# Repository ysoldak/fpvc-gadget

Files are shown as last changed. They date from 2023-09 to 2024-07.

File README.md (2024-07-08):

# FPV Combat Gadget

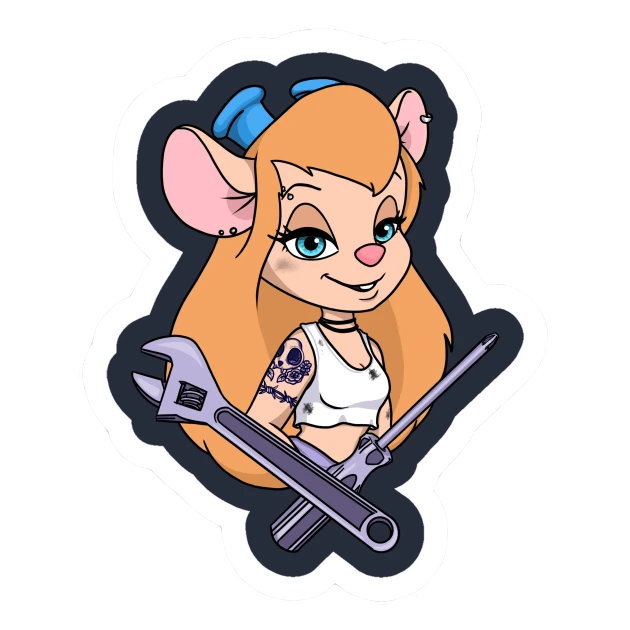
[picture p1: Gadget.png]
Gadget to your service


DIY device (gadget) that helps you quickly adjust [FPV Combat](https://www.fpv-combat.com) board settings like player ID, player name, lives, ammo and many more.

This is an alternative to classic way of using OSD menu (and IR remote earlier).  
It is a convenient way to adjust settings "on the go", at the field, for everyone.

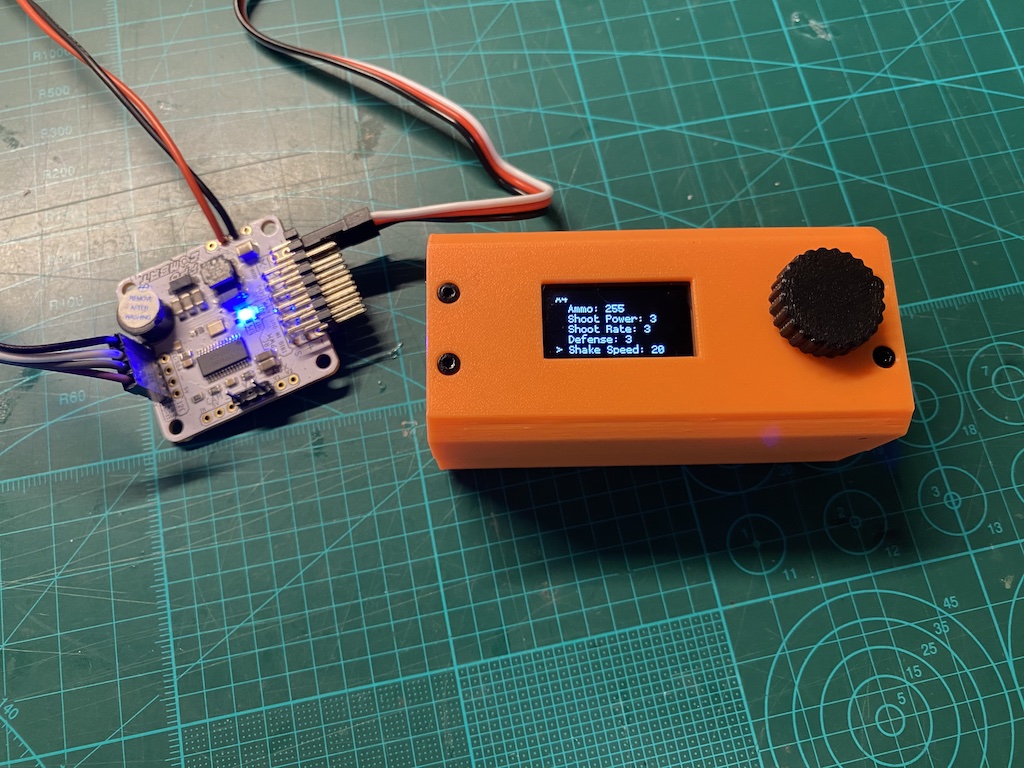
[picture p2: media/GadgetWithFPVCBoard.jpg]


FPV Combat board shall be flashed with compatible [firmware](https://github.com/FPV-Combat/Main_board_v2/releases).

**Gadget version 0.5.0+ requires FPV Combat version 2.8.0+.**

## Electronic Components

You'll need to buy some electronic components and 3D print the case, see below.  
Soldering skills required.

| Picture  | Item | Comment | Price (per item)  |
| --- | --- | --- | --- |
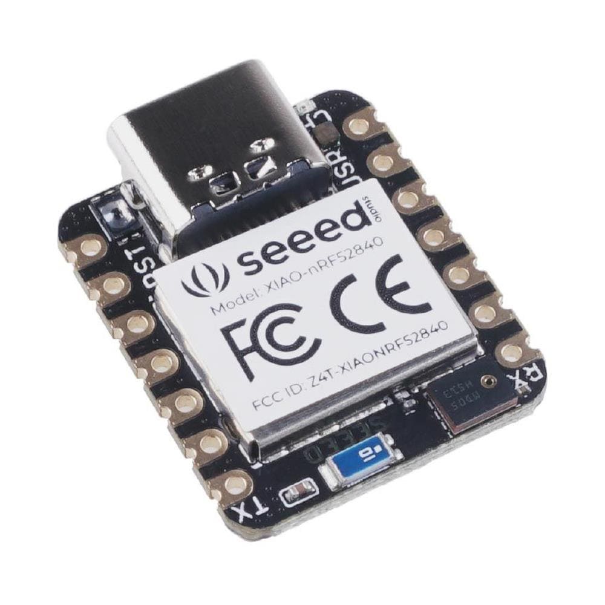
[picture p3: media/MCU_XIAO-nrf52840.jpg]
|  | [XIAO-nRF52840 board](https://www.seeedstudio.com/Seeed-XIAO-BLE-nRF52840-p-5201.html) | With battery charger | [$9.90](https://www.seeedstudio.com/Seeed-XIAO-BLE-nRF52840-p-5201.html) |
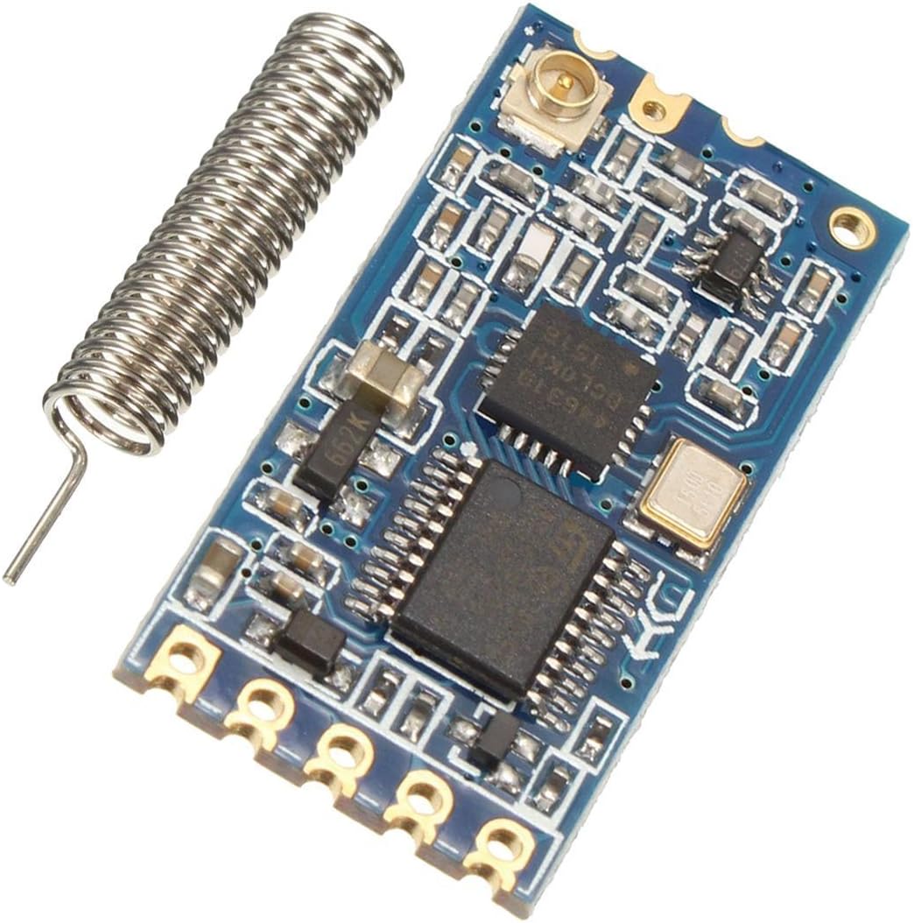
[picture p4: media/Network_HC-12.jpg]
|  | [HC-12 network module](https://www.hc01.com/goods/640e91920be12d0114404c95) | 433Mhz | $12 |
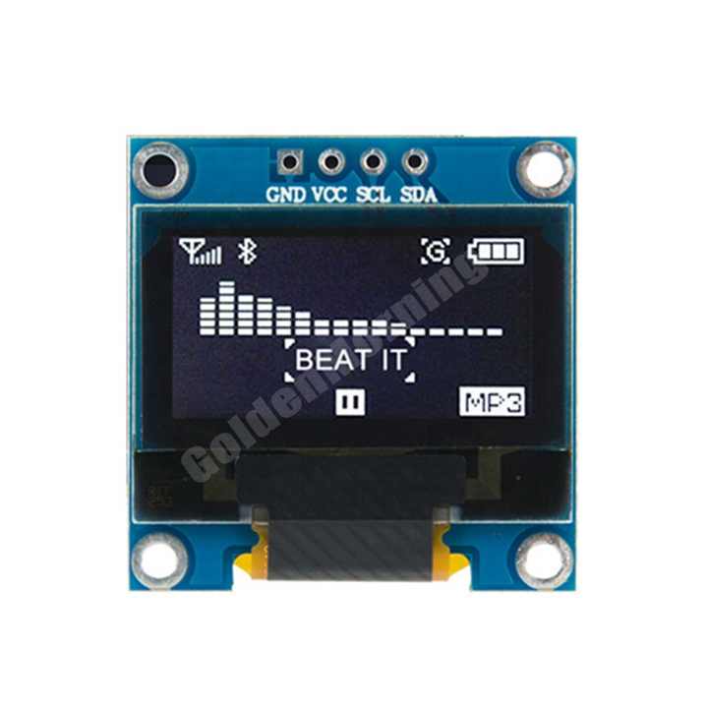
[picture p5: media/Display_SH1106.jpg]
|  | [0.96inch display](https://www.az-delivery.de/en/products/0-96zolldisplay) | OLED 128 x 64 | [$2.4](https://www.alibaba.com/product-detail/Most-Popular-GME12864-White-4pins-I2C_1600270997819.html) - [$3.8](https://www.amazon.se/dp/B074NJMPYJ) |
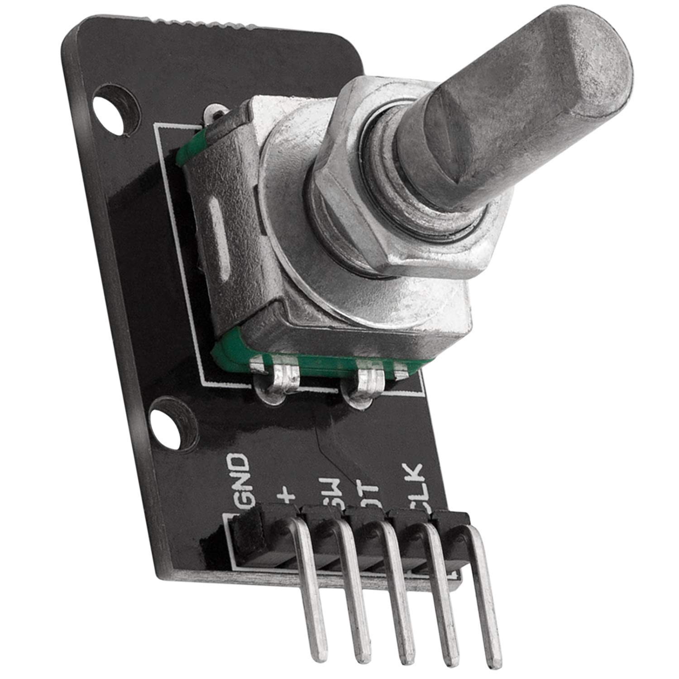
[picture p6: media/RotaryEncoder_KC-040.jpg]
|  | KY-040 rotary encoder | Breakout | [$1.8](https://www.amazon.se/dp/B07TKK4QQD) |
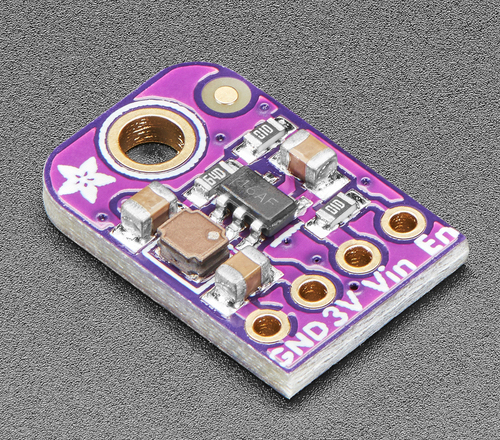
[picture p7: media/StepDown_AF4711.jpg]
|  | [Adafruit TLV62569 (4711)](https://www.adafruit.com/product/4711) | Step-down converter 3.4~5.5V to 3.3V | [$3.95](https://www.digikey.se/sv/products/detail/adafruit-industries-llc/4711/13162412) |
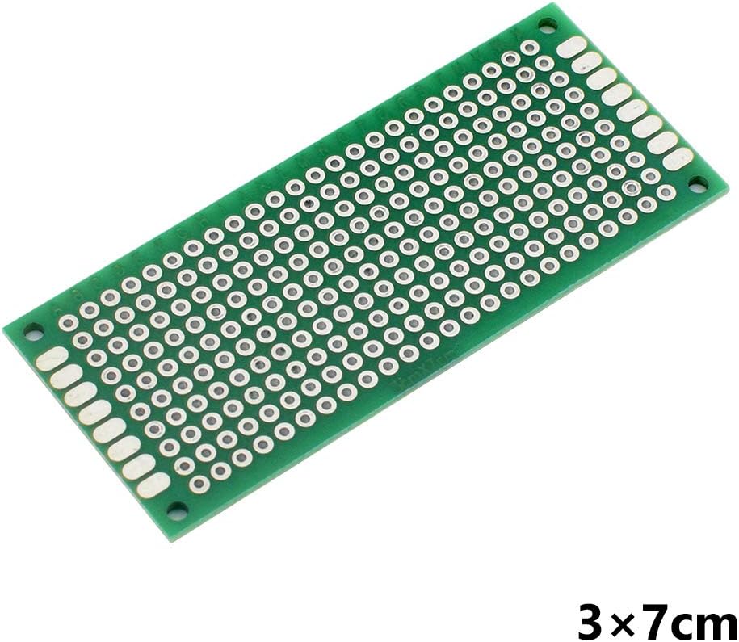
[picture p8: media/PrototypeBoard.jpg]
|  | Prototype board | 30 x 70 mm, or PCB | [$0.8](https://www.amazon.se/dp/B07CQQK214) |
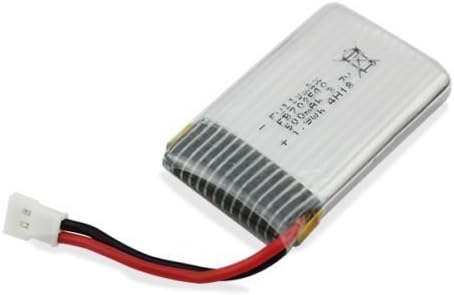
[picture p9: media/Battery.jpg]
|  | LiPo Battery | 1S, 100-500mAh, 45 x 25 x 9 mm | [$11](https://www.amazon.se/dp/B01FBSA1N6/) |
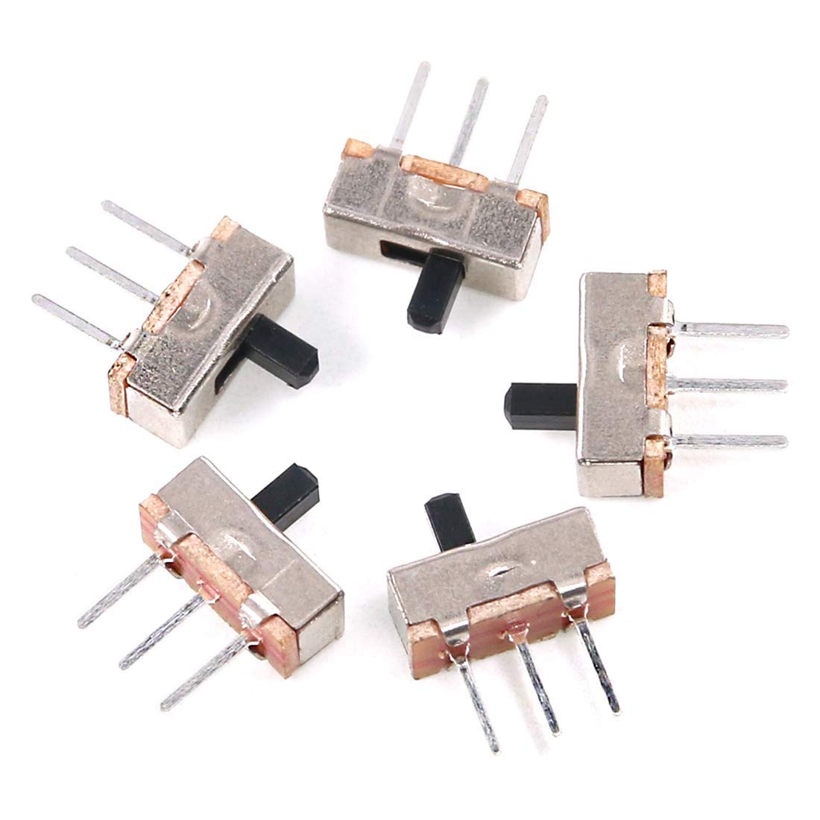
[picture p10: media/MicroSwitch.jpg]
|  | Micro Slide Switch | 2 positions, 3 contacts | [$0.1](https://www.amazon.se/Gebildet-Vertikal-Switch-SS-12d00-Position/dp/B08L6FMV84/?th=1) | 
| **Total** ||| **$45** |

### Alternatives
- MCU
  - [XIAO-RP2040](https://www.seeedstudio.com/XIAO-RP2040-v1-0-p-5026.html) - $5.40 (cheaper, no battery charger)
  - [XIAO-nRF52840 Sense](https://www.seeedstudio.com/Seeed-XIAO-BLE-Sense-nRF52840-p-5253.html) - $15.99 (more expensive, has IMU that we don't use)
- Step-down converter
  - [LM3671](https://www.adafruit.com/product/2745) - $4.95
  - [TPS62827](https://www.adafruit.com/product/4920) - $6.95
  - [DFR0568](https://www.dfrobot.com/product-1765.html) - $2.9
- Battery charger (optional, use with MCU w/o built-in battery charger)
  - [Greluma 6st](https://www.amazon.se/dp/B09WMVLWH5)

## Assembly

It is possible to [order the gadget](https://www.etsy.com/se-en/listing/1589030767/fpv-combat-gadget-battery-not-included) either fully assembled, as a kit or just PCB from [our shop on Etsy](https://www.etsy.com/se-en/shop/SkyGadgets).

Alternatively, you can always order PCB yourself from PCBWay, JLCPCB and alike or use 30x70mm prototype board.

### Assembly tips

- Once soldered, backs of pins/slots have to be filed out/flattened, otherwise risk of damaging the battery;
- Straighten encoder pins and cut them a bit, just a several mm;
- Cut a bit of encoder pcb, across mounting holes, otherwise it does not fit;
- HC-12 is placed white (flat) side up;
- Pull HC-12 antenna a little so it is away from everything to minimise interference.

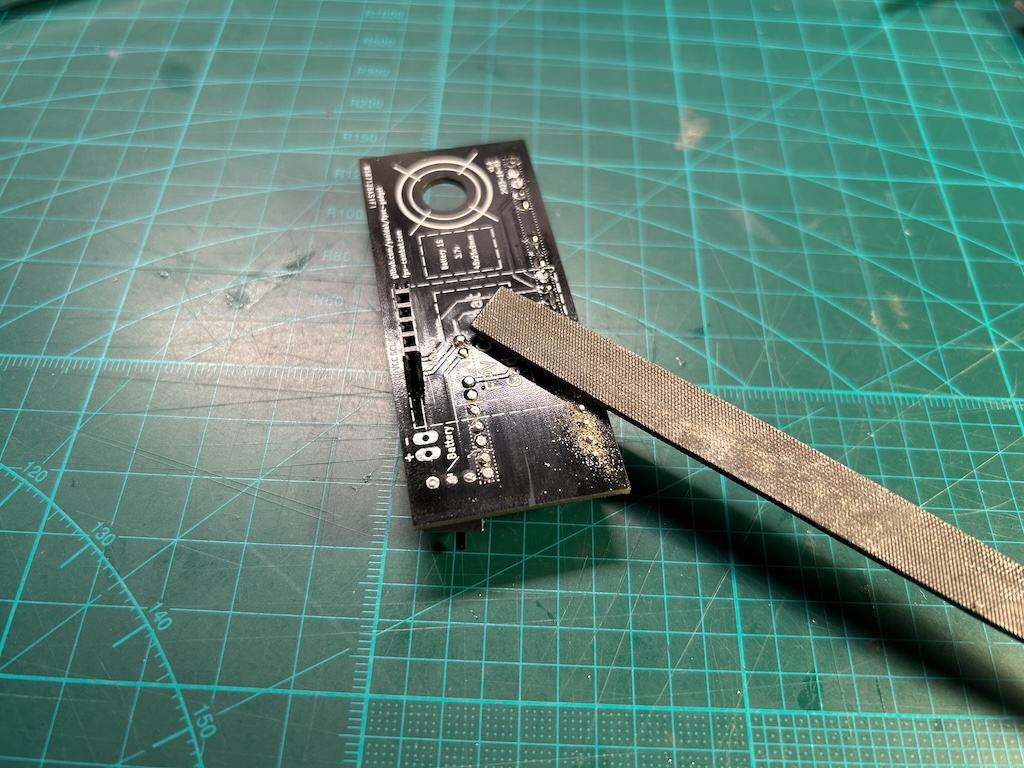
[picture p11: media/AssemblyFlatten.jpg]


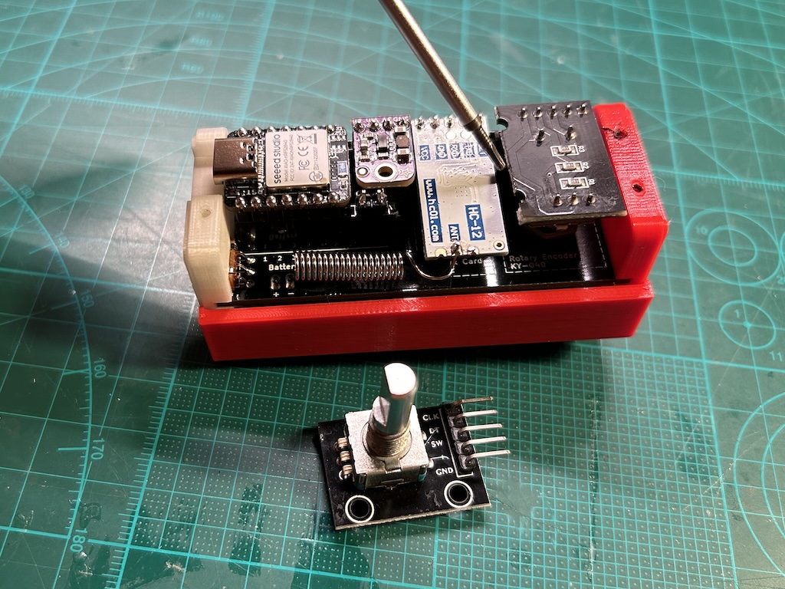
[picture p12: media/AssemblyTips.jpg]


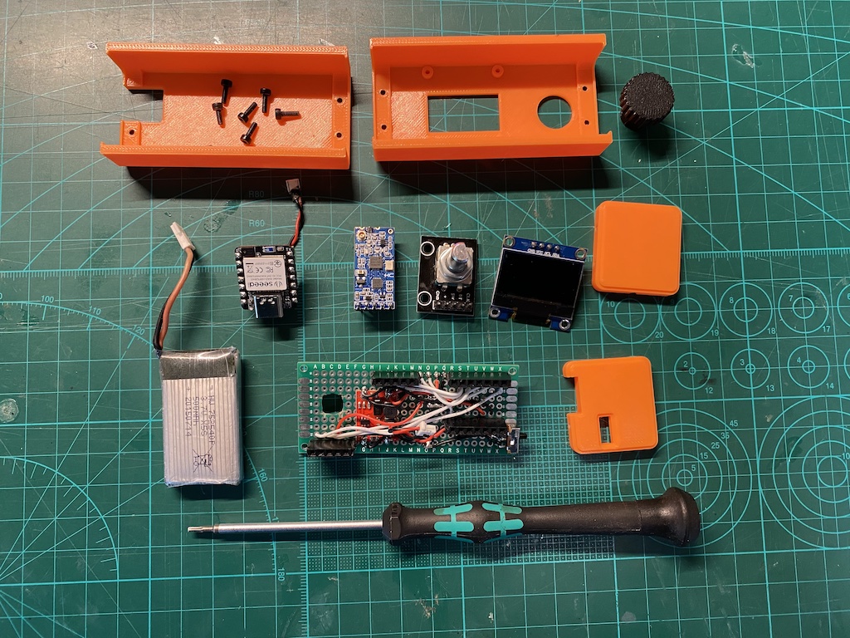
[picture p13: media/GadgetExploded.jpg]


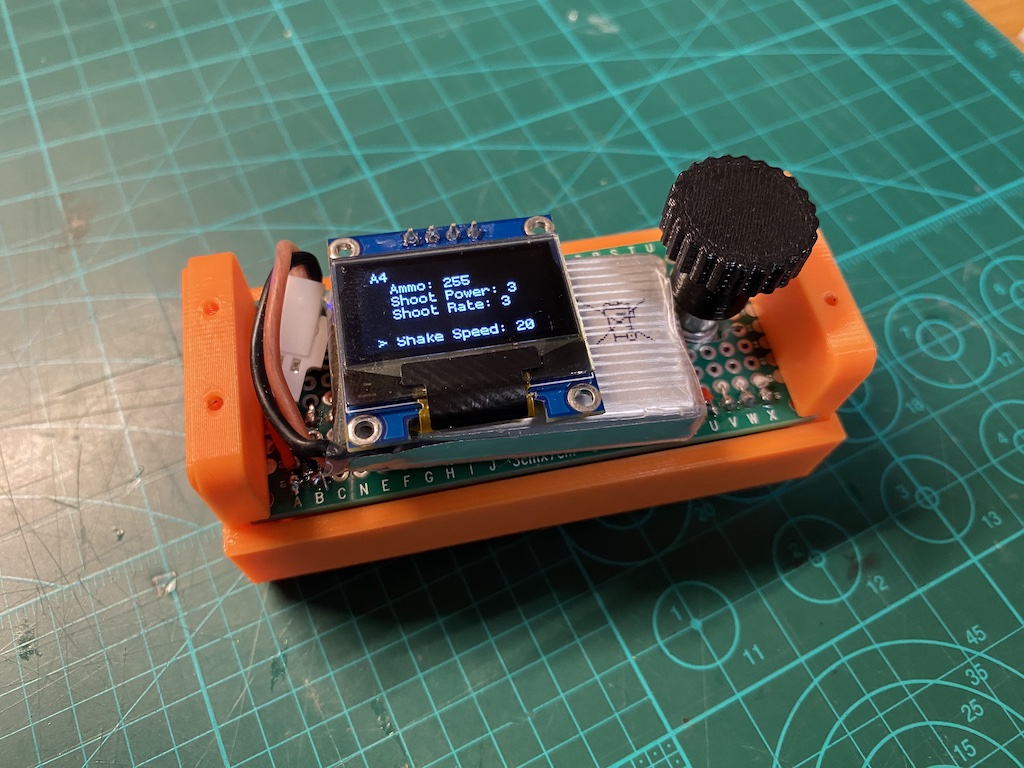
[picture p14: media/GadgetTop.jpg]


### Schematic

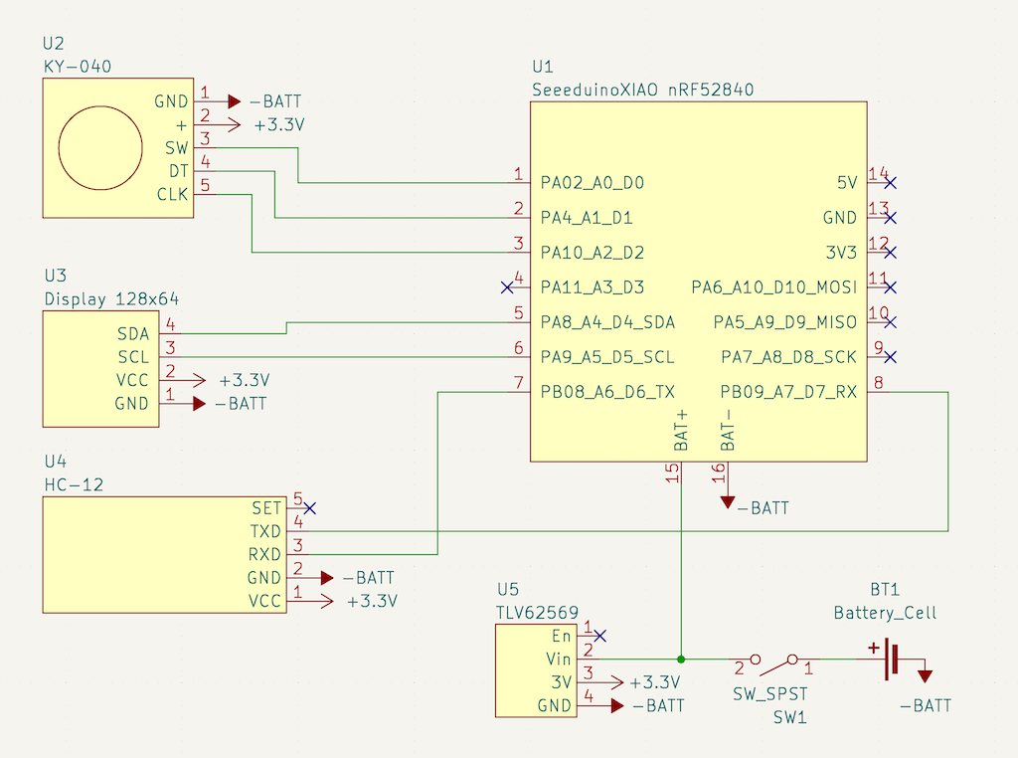
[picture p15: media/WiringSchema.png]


### PCB

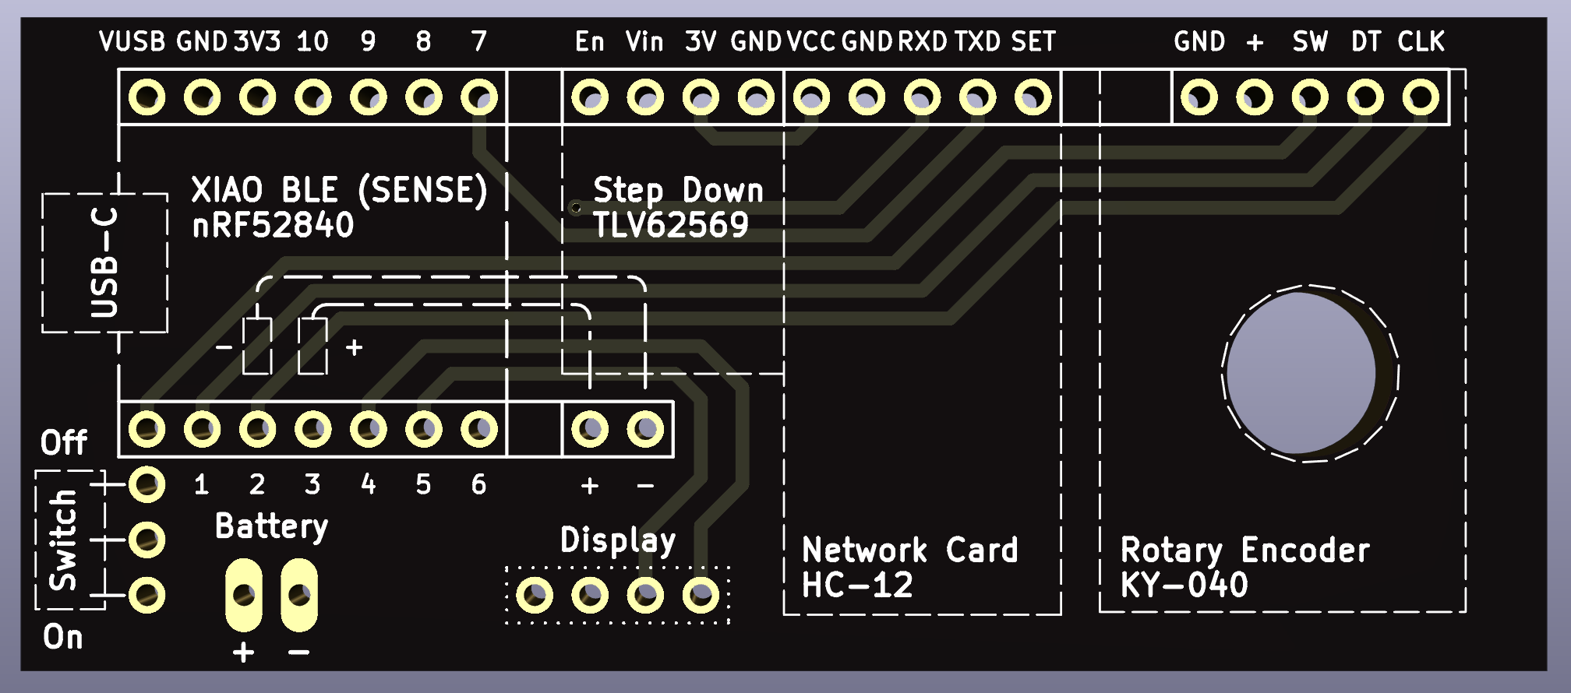
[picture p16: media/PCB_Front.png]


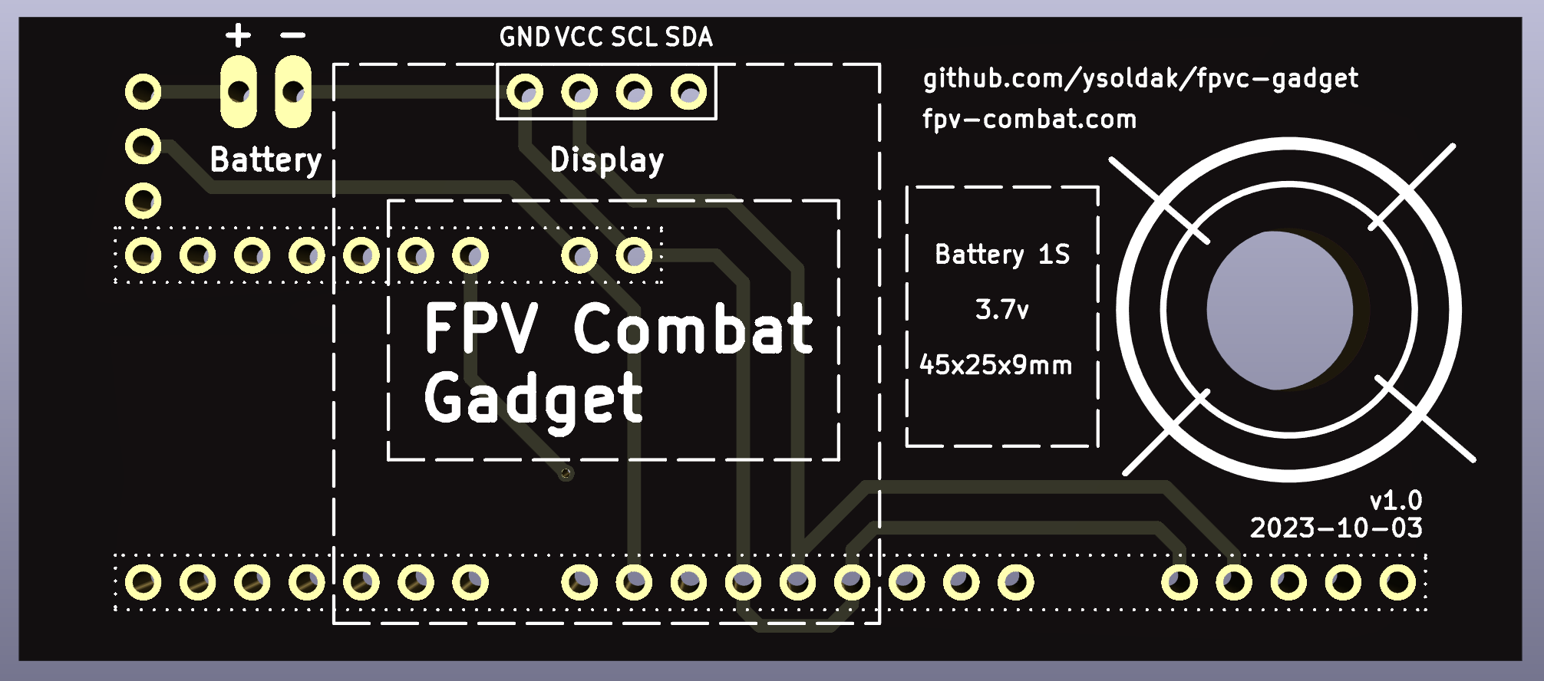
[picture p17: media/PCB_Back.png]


## Contacts

Join our [FPV-Combat Community](https://www.facebook.com/groups/2441262976051510/)

Questions? [Make an issue](https://github.com/ysoldak/fpvc-gadget/issues) on this repository or search Yurii Soldak in our FB group.

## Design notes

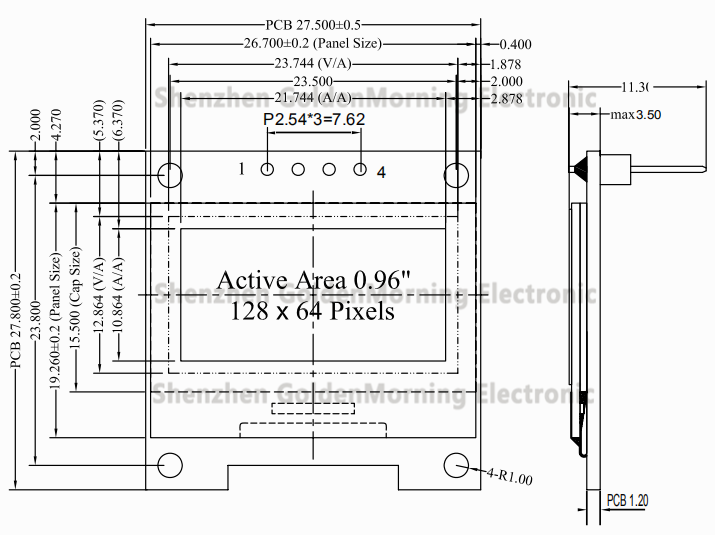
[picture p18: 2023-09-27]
media/DisplayDimensions.png

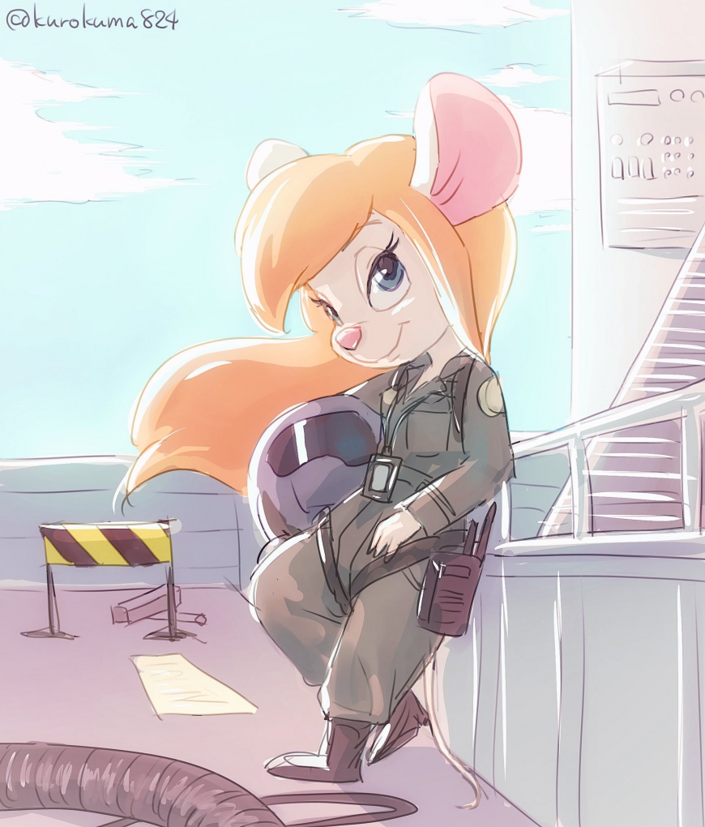
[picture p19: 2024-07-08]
media/GadgetLovesYou.jpg

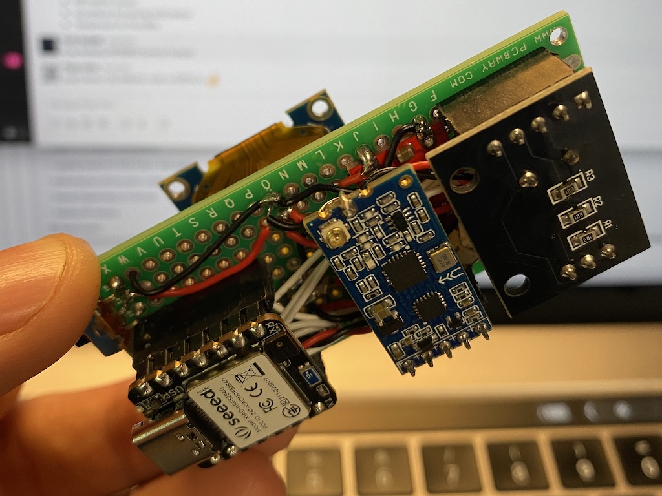
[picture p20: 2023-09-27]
media/GadgetBottom.jpg

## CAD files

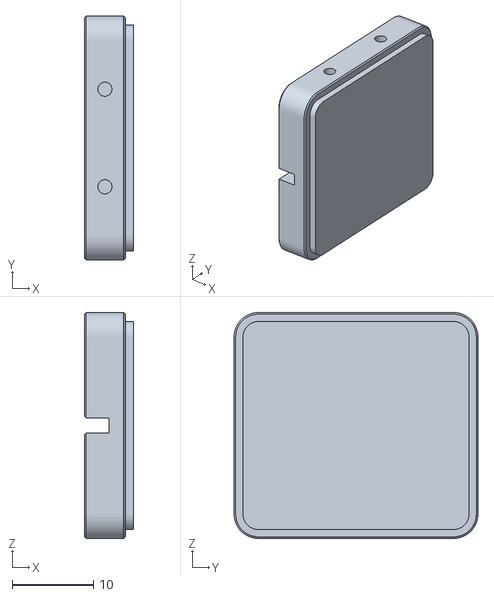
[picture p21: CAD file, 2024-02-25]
case/Right.stl
6.00 x 30.0 x 27.8

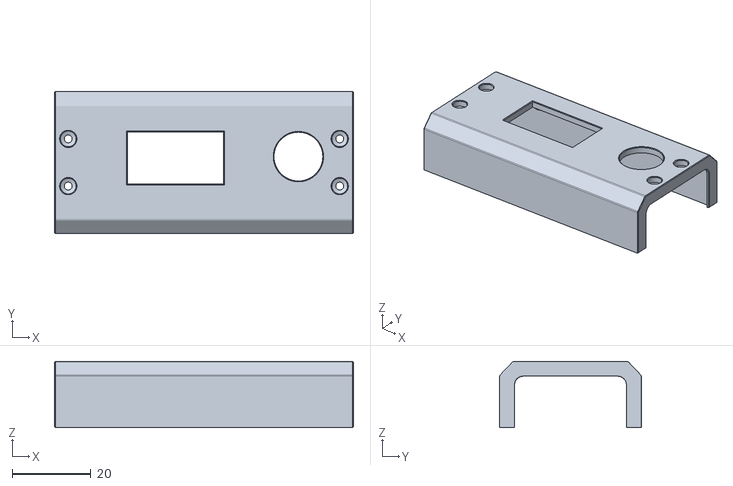
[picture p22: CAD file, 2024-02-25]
case/Top.stl
76.0 x 36.0 x 16.9

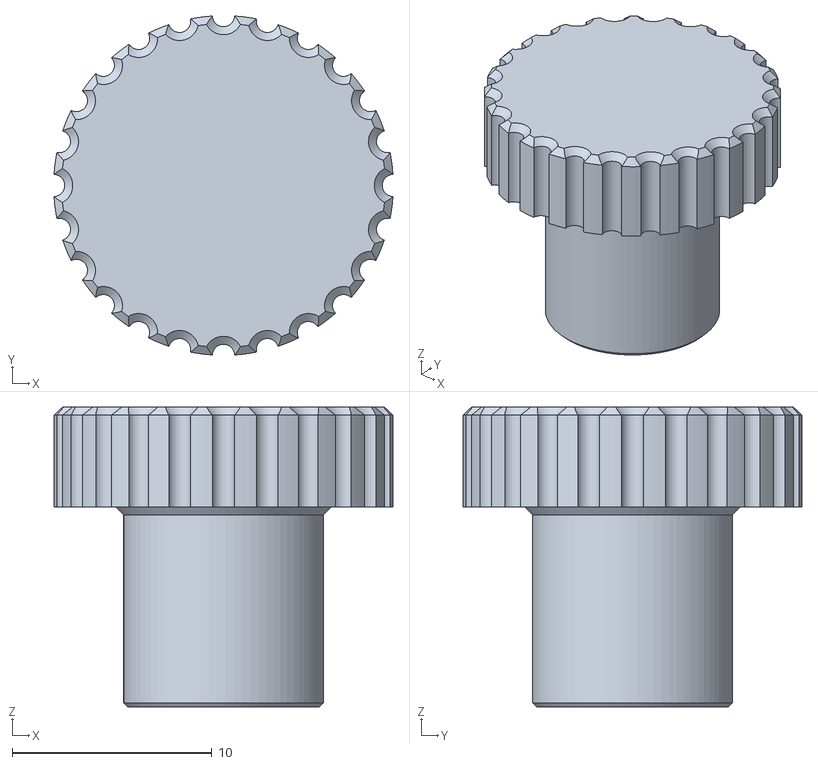
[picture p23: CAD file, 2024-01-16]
case/Knob.stl
17.0 x 17.0 x 15.0

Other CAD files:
case/Left.stl
case/Bottom.stl
case/Gadget.f3d

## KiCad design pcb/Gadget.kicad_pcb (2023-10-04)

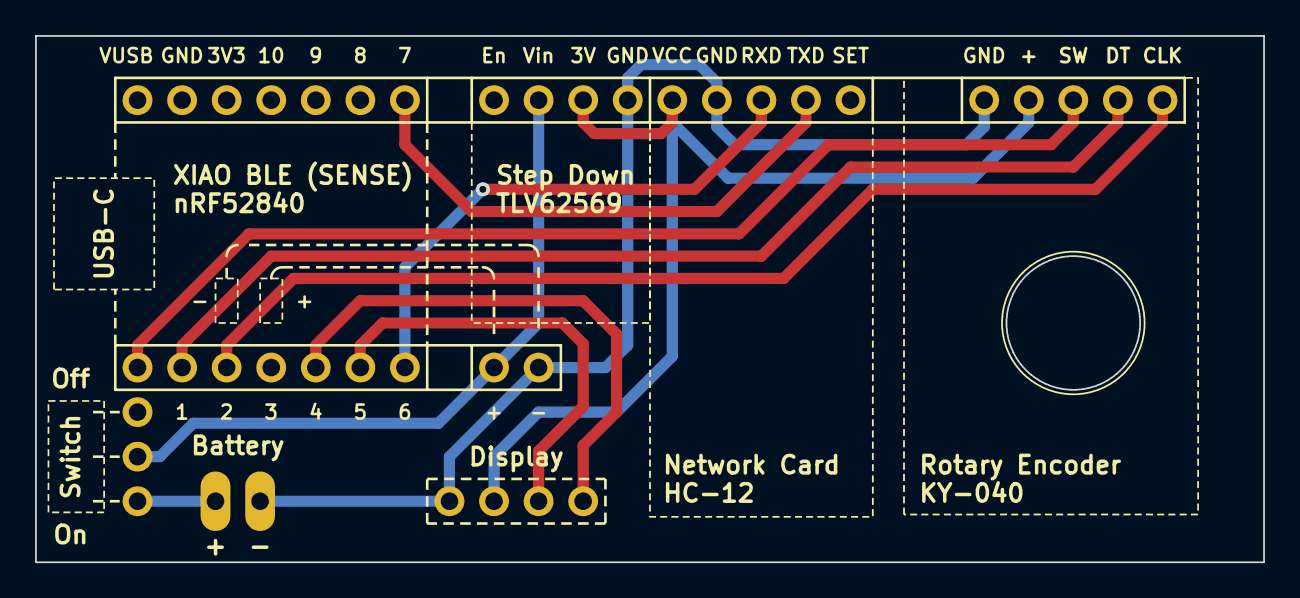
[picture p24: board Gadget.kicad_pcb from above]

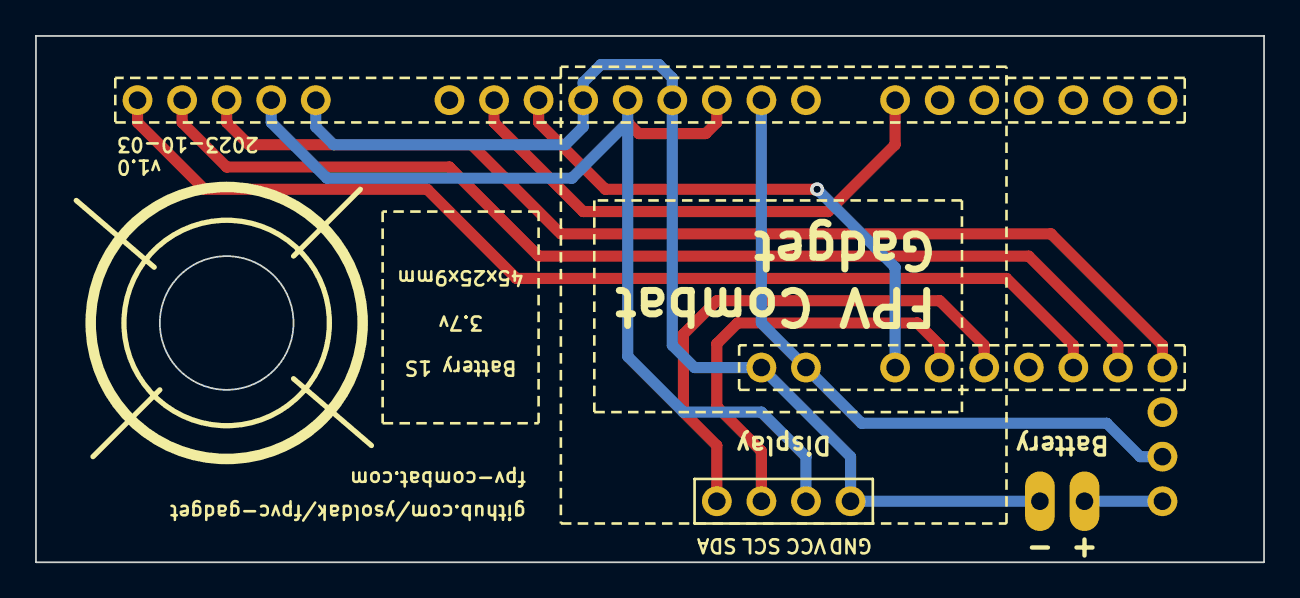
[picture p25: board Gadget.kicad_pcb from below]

Board: 2 copper layers, 70.0 x 30.0 mm, 7 parts (2 on the bottom side), 11 nets.

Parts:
BT1: Battery_Cell; Battery Connector
SW1: SW_SPST; Switch
U1: SeeeduinoXIAO nRF52840; XIAO-NRF52840
U2: KY-040; RotaryEncoder KY-040
U3: Display 128x64; Display 0.96 128x64
U4: HC-12
U5: TLV62569

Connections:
+3.3V: U2.2 (+), U3.2 (VCC), U4.1 (VCC), U5.3 (3V)
-BATT: BT1.2 (-), U1.16 (BAT-), U2.1 (GND), U3.1 (GND), U4.2 (GND), U5.4 (GND)
unnamed: BT1.1 (+), SW1.1 (A)
unnamed: SW1.2 (B), U1.15 (BAT+), U5.2 (Vin)
unnamed: U1.1 (PA02_A0_D0), U2.3 (SW)
unnamed: U1.2 (PA4_A1_D1), U2.4 (DT)
unnamed: U1.5 (PA8_A4_D4_SDA), U3.4 (SDA)
unnamed: U1.6 (PA9_A5_D5_SCL), U3.3 (SCL)
unnamed: U1.3 (PA10_A2_D2), U2.5 (CLK)
unnamed: U1.7 (PB08_A6_D6_TX), U4.3 (RXD)
unnamed: U1.8 (PB09_A7_D7_RX), U4.4 (TXD)

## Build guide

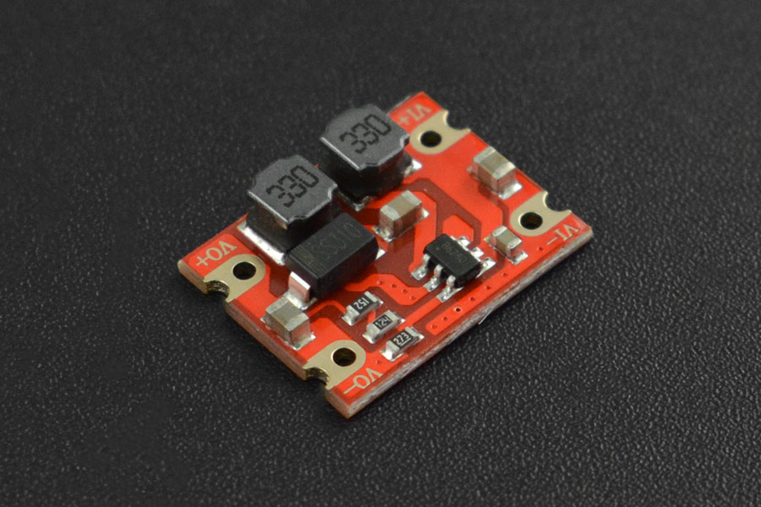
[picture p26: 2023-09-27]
media/StepDown_DFR0568.jpg

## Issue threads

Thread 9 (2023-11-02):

Micro Companion? The Lady´s daughter

MrMap, 2023-11-02:
Since The Gadget has access to the combat radio network...
Could it be made to act as a barebone combat game score counter? (if provided with a good enough antenna)

Could be useful for simple combat events, maybe only digital video participants, where the full-grown Lady has been left home (or not yet acquired by the user group) - to do and present basic score count that would otherwise/previously be available on the analog system.

ysoldak, 2023-11-02:
Great idea! Yes, for sure the gadget can be extended to do that. Need to fix firmware and hardware for that too. Hardware is as you mentioned we want to have better antenna then, to “hear” all events. Could be SMA port to optionally attach an external antenna. Not sure if will need to remove the spring antenna in that case then or both antennae can work together and do not conflict.

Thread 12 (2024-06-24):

Gadget stops responding when changing the name

chaos5235, 2024-06-24:
Gadget stops responding when changing the name
- at the point when the name gets changed/saved

- HW 2.4
- FW: 2.8.0 beta

ysoldak, 2024-06-24:
Happens only with name change? Other settings change (and save) fine?

chaos5235, 2024-06-24:
happened with all 3 boards that i tested - just when name was changed

ysoldak, 2024-07-08:
Please try with 0.5.1

ysoldak, 2025-02-05:
@chaos5235 still problem?

chaos5235, 2025-02-05:
will check ;)

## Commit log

2023-08-15 Filter invalid values
2023-09-15 Bill of materials
2023-09-27 Prepare for release
    [Bottom.stl, Gadget.f3d, Knob.stl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]
2023-10-01 Show battery voltage on start
2023-10-03 PCB design (#6)
    [Gadget.kicad_pcb, Gadget.kicad_sch]
2023-10-04 pcb change after output
    [Gadget.kicad_pcb]
2023-10-16 Adjust case to match PCB (#7)
    [Bottom.stl, Gadget.f3d, Left.stl]
2023-10-16 Update README.md
    - Removed link to bad Amazon item
    - Added links to some items
    - Added link to Etsy shop (order gadget, kit or PCB)
2023-10-16 Assembly tips
2023-10-30 Assorted mini fixes (#8)
    Device page: cursor is at first device setting on page open
    Device page: can go back even after config fetch failure
    Device page: "Addr Led" renamed to "Team Led"
    Device page: show device description (contains just firmware version as of FW 2.5.0)
    Device page: wrap cursor up and down
    Scan page: Ignore invalid device IDs during scan
    All: UI elemnts positions adjusted a bit
2024-01-16 New knob, prints better with 0.4mm nozzle and 95% flow
    [Knob.stl]
2024-02-25 Update case STLs
    [Gadget.f3d, Left.stl, Right.stl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]
2024-05-12 Cleanup unsupported HW 2.5 pin settings + some renames (#11)
    CSP stands for Combat Serial Protocol
    FC is Flight Controller
    AU is Air Unit (digital VTX)
2024-07-07 CSP Protocol Update (#13)
    * device: set player number
    * CSP protocol update
    * CSP fixes
    * Assorted CSP fixes
2025-06-04 Support MSP AU on HW25 (#14)
    * Support MSP AU on HW25
    Also:
    - Fixes ports configuration on HW26
    - Adds Settings address constants
    * Bump versions in workflows
    * Initialize ADC in Battery configuration
